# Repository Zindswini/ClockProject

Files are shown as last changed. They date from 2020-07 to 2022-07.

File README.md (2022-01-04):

# ClockProject V2.0
This is the GitHub Companion to the Large scale RGB LED Clock as shown in [VIDEO IN PROGRESS]
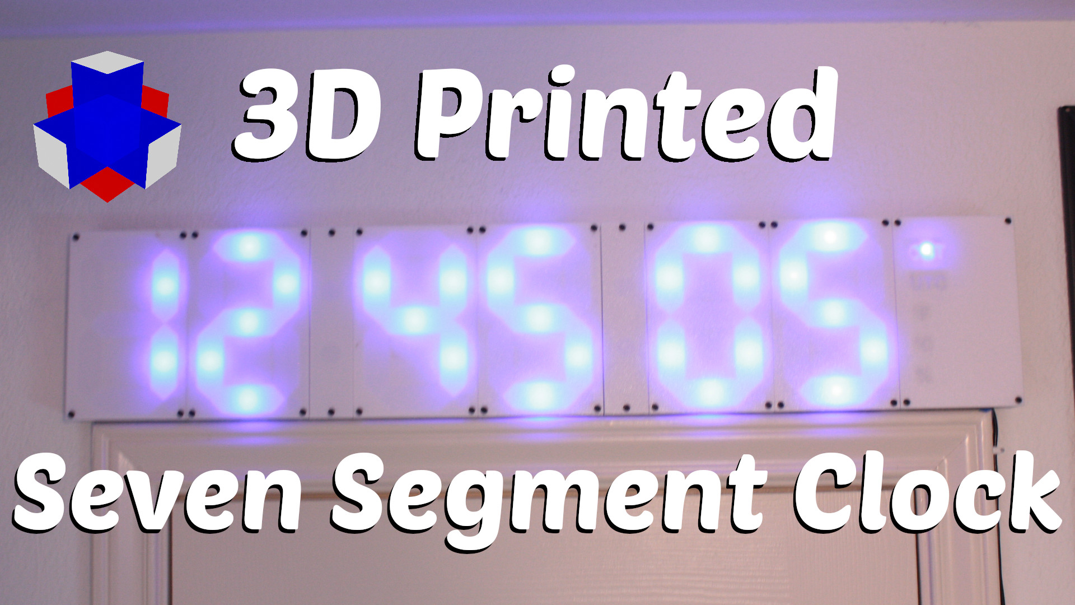
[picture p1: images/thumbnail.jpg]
Thumbnail
 
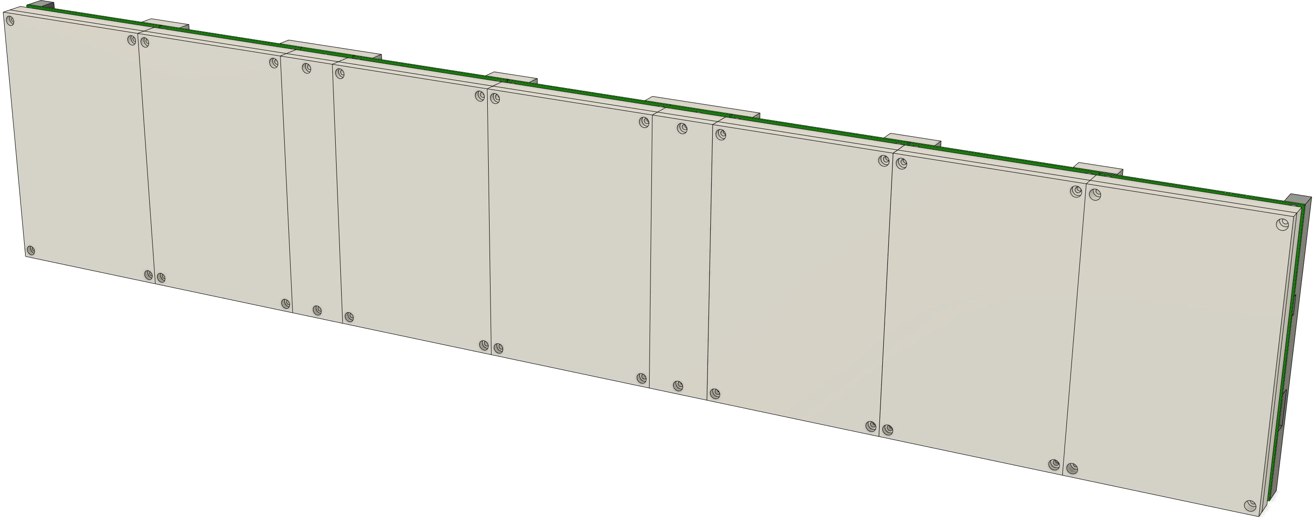
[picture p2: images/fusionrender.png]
Fusion Render
TablePicture 

# Design Files
- 3D and Circuit design was completed using Autodesk Fusion 360. Exports from the project are provided.
- Manufacturing was completed through JLC PCB, Gerber files exported from Fusion 360 are provided.

# Dependencies & Building
This project uses PlatformIO to manage dependencies. In theory, this should mean that you will not have to worry about dependencies and versioning. Just in case, a list of used libraries is provided below.

In order to program your own clock, you need to provide the appropriate credentials for your Wifi network. In order to connect, update the STASSID and STAPSK fields.

This project relies on:
### Libraries:
- [Adafruit ESP8266](https://github.com/adafruit/Adafruit_ESP8266) (In Library Browser)
- [Arduino JSON](https://github.com/bblanchon/ArduinoJson/tree/5.x)  (In Library Browser) (*Note version 5.x*)
- [DHTesp](https://github.com/beegee-tokyo/DHTesp) (In Library Browser)
- [NTPClient](https://github.com/arduino-libraries/NTPClient) (In Library Browser)
- [TelnetStream](https://github.com/jandrassy/TelnetStream) (In Library Browser)

### ESP Board
Add http://arduino.esp8266.com/stable/package_esp8266com_index.json to the "Additional Board Manager URLs" in the Arduino IDE, then add the esp8266 from inside the board manager.

Be sure to select "Adafruit Feather HUZZAH ESP8266" when compiling.

(this might be obsolete now that the project uses PlatformIO)

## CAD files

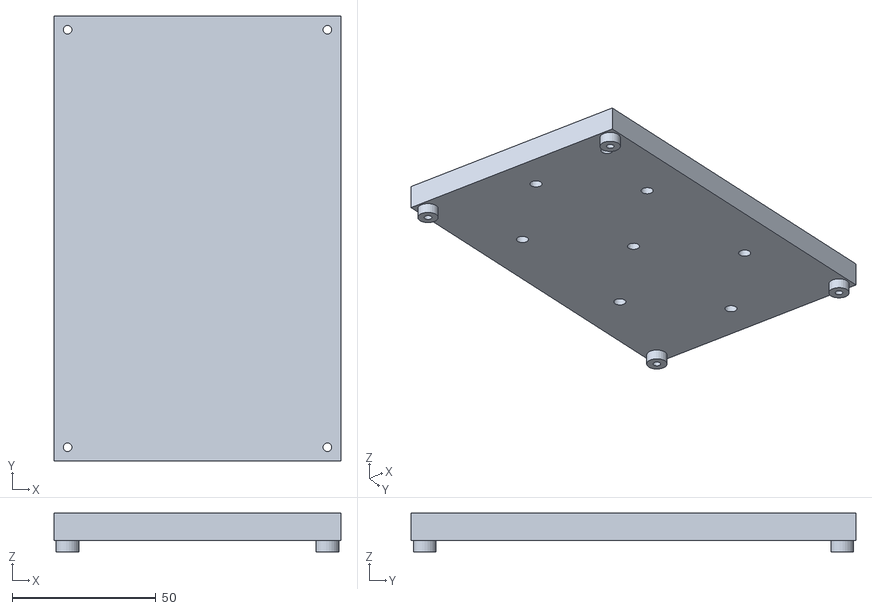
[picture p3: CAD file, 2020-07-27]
3D Files/STLs/Display Back Plate.stl
100.0 x 155.0 x 13.5

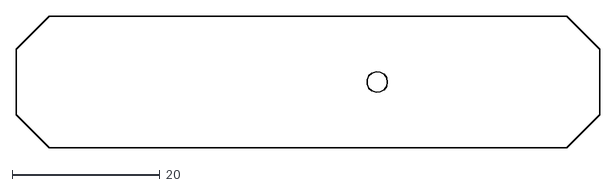
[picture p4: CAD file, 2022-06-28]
cad/3D/pcb_profile.dxf
79.1 x 17.8

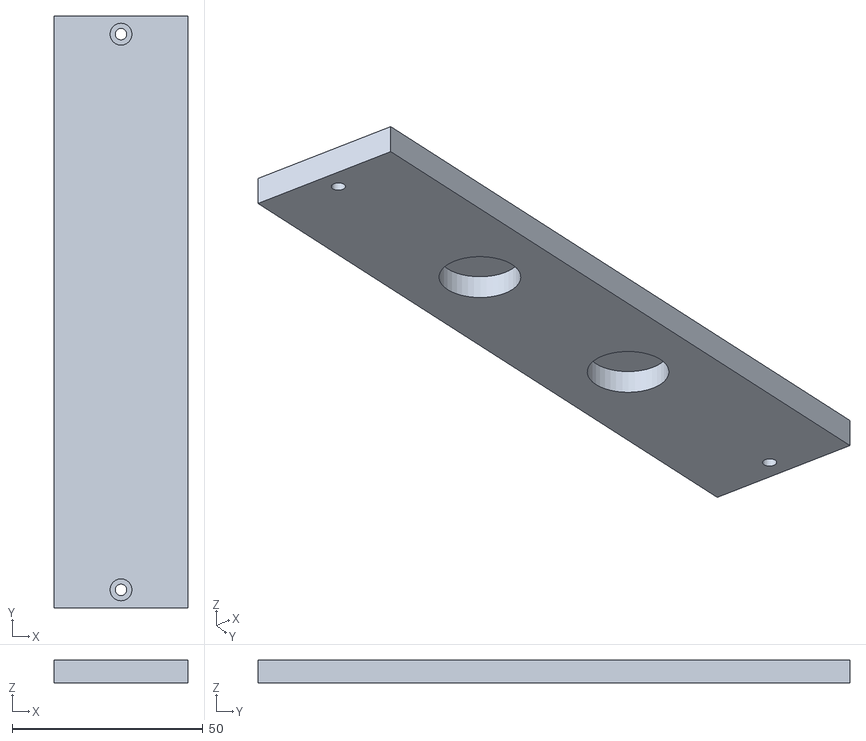
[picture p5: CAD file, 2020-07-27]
3D Files/STLs/Tick Front Plate.stl
35.0 x 155.0 x 6.00

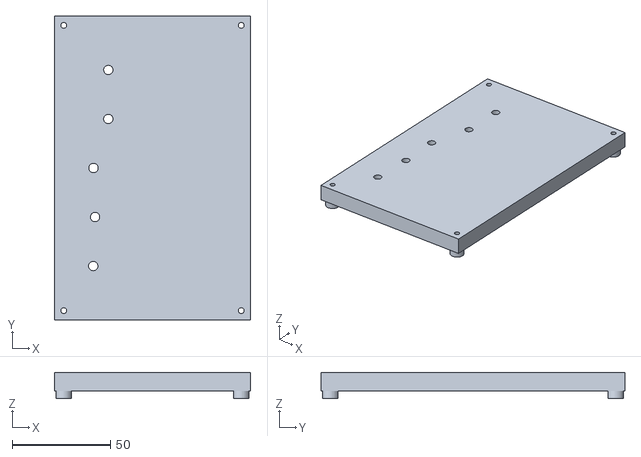
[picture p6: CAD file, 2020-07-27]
3D Files/STLs/Controller Back Plate.stl
100.0 x 155.0 x 13.5

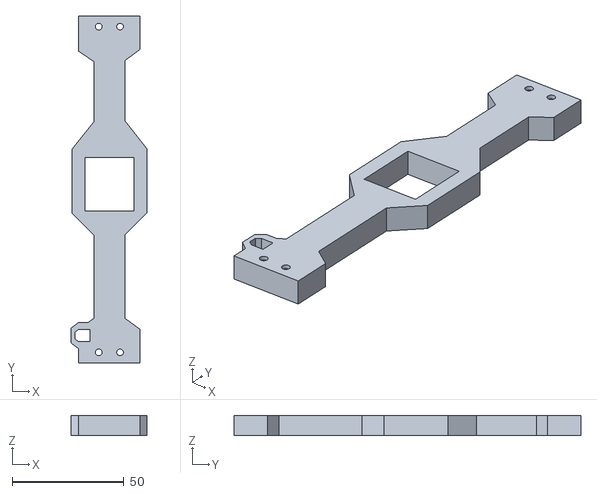
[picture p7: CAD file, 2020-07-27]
3D Files/STLs/Display Joiner.stl
33.9 x 155.0 x 9.00

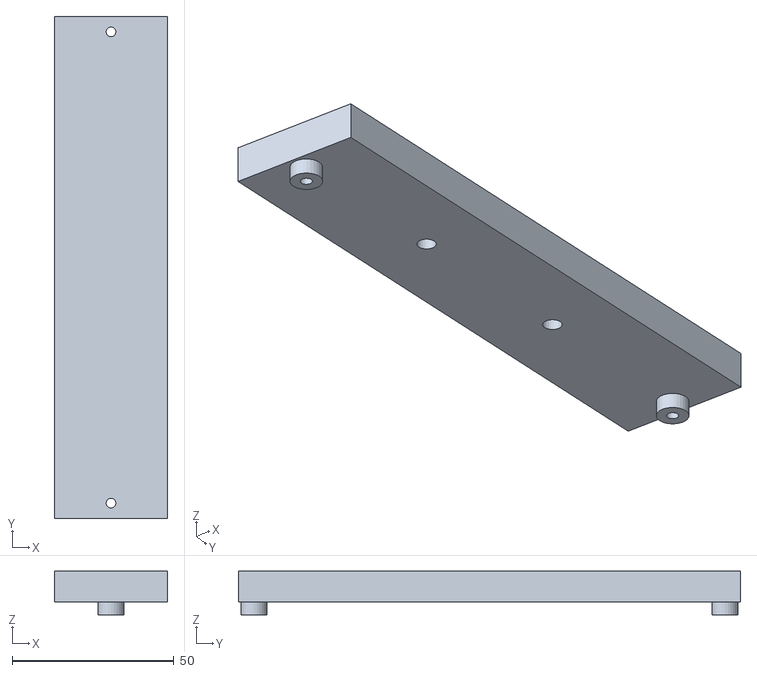
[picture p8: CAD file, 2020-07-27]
3D Files/STLs/Tick Back Plate.stl
35.0 x 155.0 x 13.5

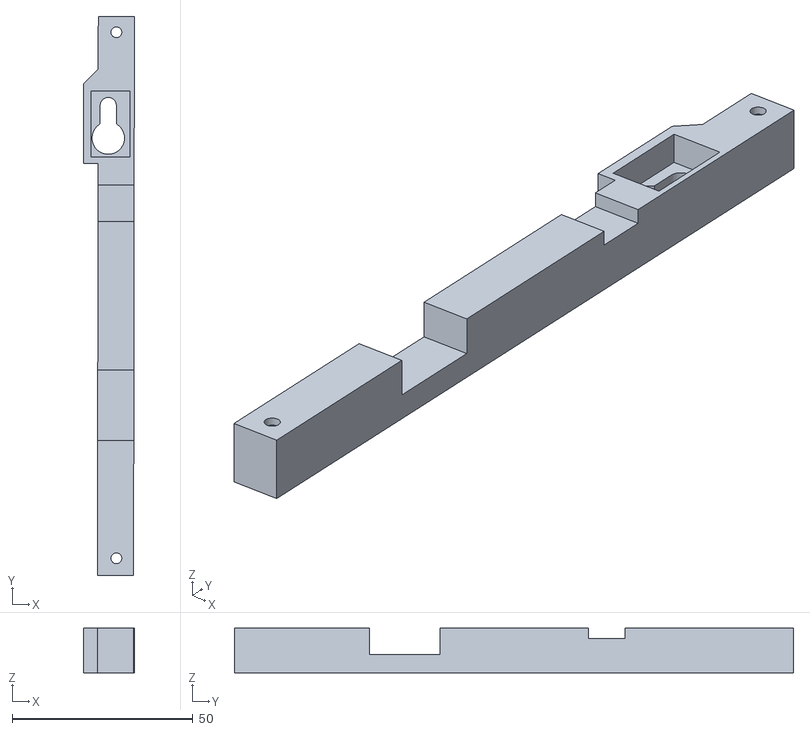
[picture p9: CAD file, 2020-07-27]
3D Files/STLs/Right Wall Mount.stl
14.1 x 154.6 x 12.4

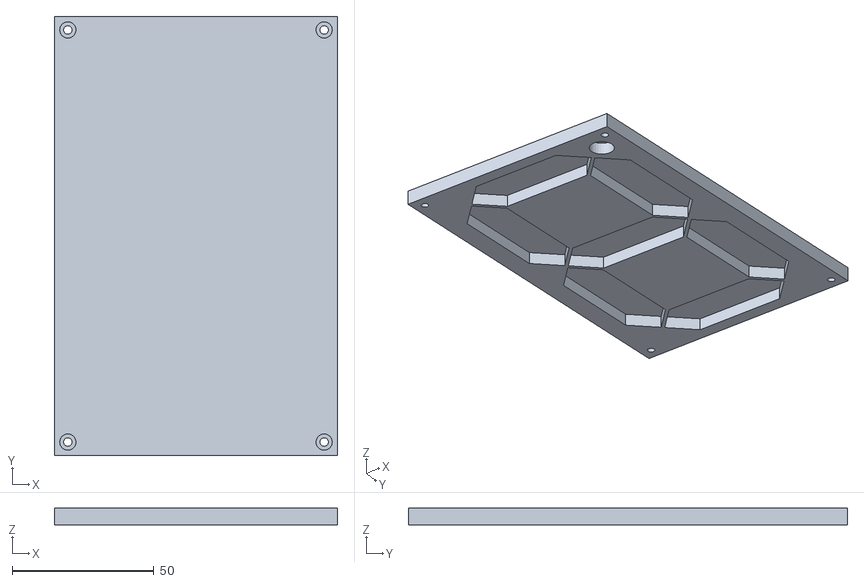
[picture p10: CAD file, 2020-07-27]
3D Files/STLs/Display Front Plate.stl
100.0 x 155.0 x 6.00

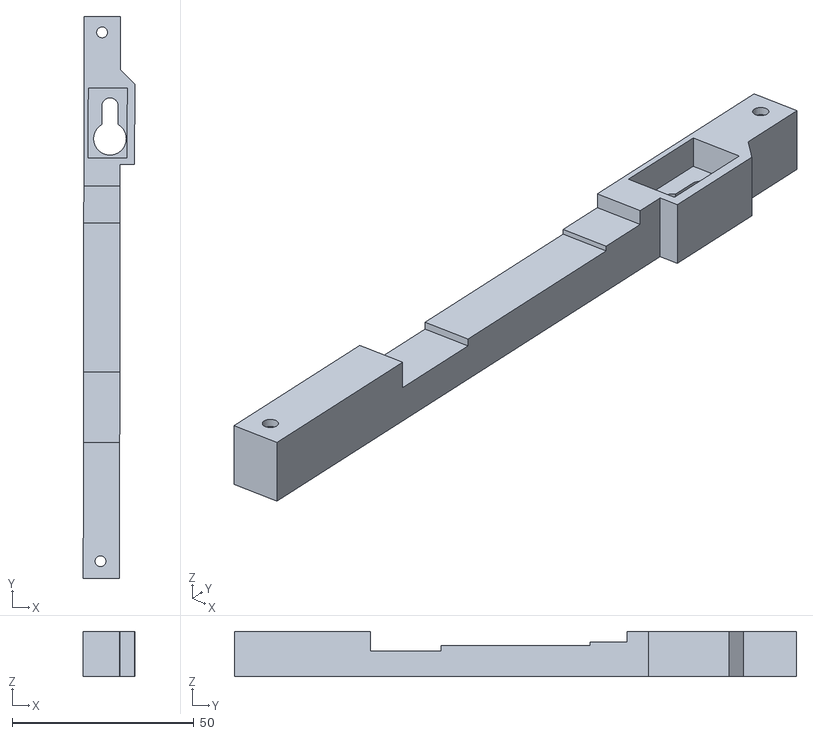
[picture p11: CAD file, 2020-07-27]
3D Files/STLs/Left Wall Mount.stl
14.2 x 154.6 x 12.4

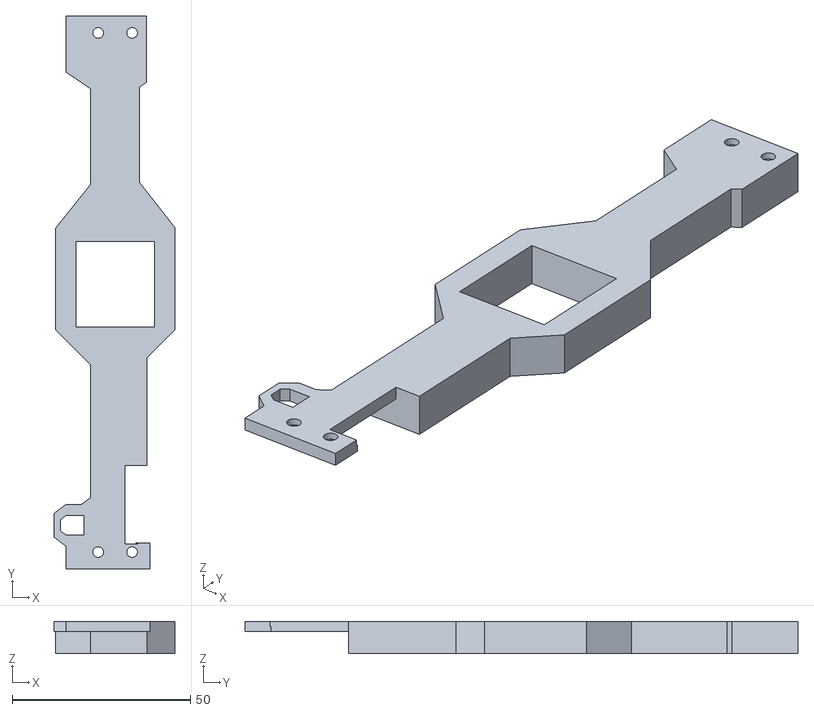
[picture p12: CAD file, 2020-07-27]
3D Files/STLs/Controller Joiner.stl
33.9 x 155.0 x 9.00

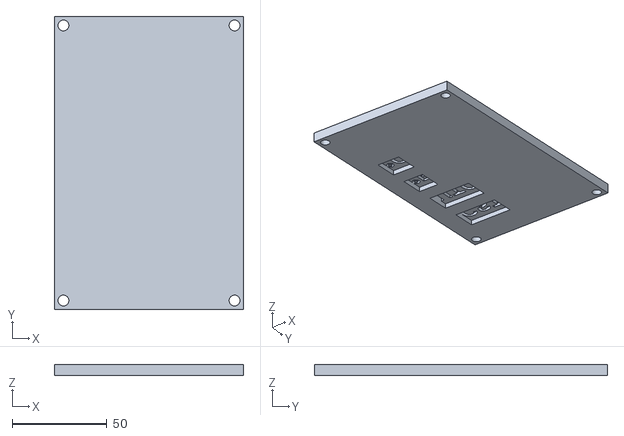
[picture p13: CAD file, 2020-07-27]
3D Files/STLs/Controller Front Plate.stl
100.0 x 155.0 x 6.00

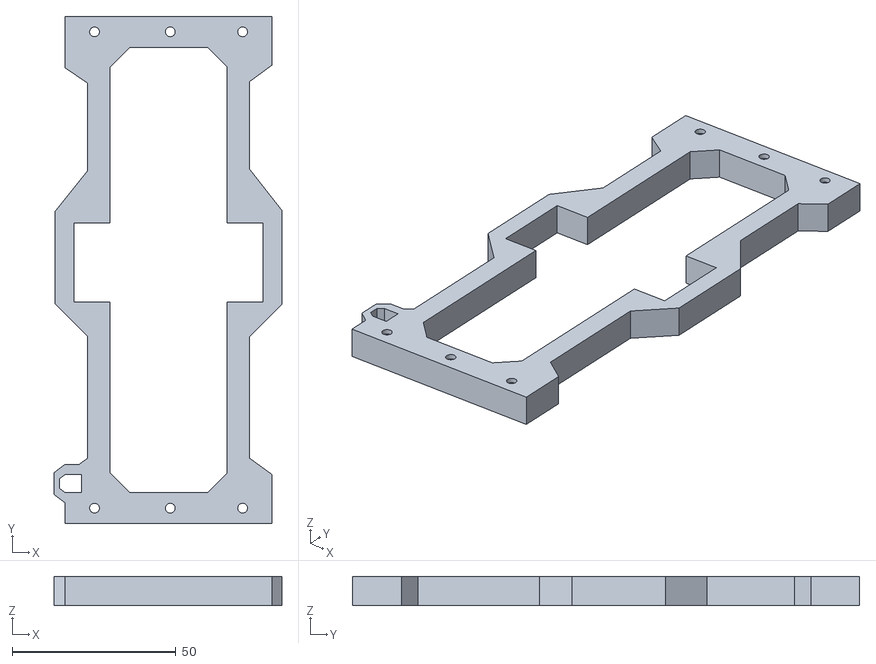
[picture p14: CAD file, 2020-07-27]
3D Files/STLs/Tick Joiner.stl
69.7 x 155.0 x 9.00

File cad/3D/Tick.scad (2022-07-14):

$fn=15;
panel_Height=160;

// Derived Variables
grid = panel_Height / 16;
panel_Width=grid*10;


//Led spacing parameters
led_side_width=6;
led_package_depth=4;

//Chamber Parameters
circle_diameter=grid*1.65;
midpoint_spacing=grid*1.65;
chamber_depth=4;

//Top Diffuser Parameters
diffuse_depth=0.75;


//ETC
screw_diameter=2.8;
screw_distance=1.5*grid;

bridging_helper_size=0.2;
bridging_padding = 1;

chanfer = 5;

pcb_depth = 3;

led_depth = led_package_depth + pcb_depth;

//Show/hide elements
led_layer = true;
chamber = false;
bridge_helpers = false;
diffuse_layer = false;

pcb_mode = false;

if (pcb_mode){
    led_layer = false;
    chamber = false;
    bridge_helpers = false;
    diffuse_layer = false;
    pcb_depth = 0;
    
    pcb_link([0,0,0], 0, true);
}



//Define major points
a = [5 * grid, 14 * grid, 0];
b = [8 * grid, 11 * grid, 0];
c = [8 * grid, 5 * grid, 0];
d = [5 * grid, 2 * grid, 0];
e = [2 * grid, 5 * grid, 0];
f = [2 * grid, 11 * grid, 0];
g = [5 * grid, 8 * grid, 0];
//h = [1 * grid, 1 * grid, 0];

points = [a, b, c, d, e, f, g];

render() difference(){
    union(){
        //Led Layer
        if (led_layer) difference() {
            cube([panel_Width, panel_Height, led_depth]);
            for(i=points)
            {
                translate(i - [led_side_width/2, led_side_width/2, 0])
                    cube([led_side_width, led_side_width, led_depth], false);
            }
        }
        
        
        //Chamber Layer
        if(chamber){
            translate([0, 0, led_depth]){
                difference() {
                    cube([panel_Width, panel_Height, chamber_depth]);
                    
                    //Horizontal
                    for(i=[a, d, g]) { chamber(i, 0); }
                    
                    //Vertical
                    for(i=[b, c, e, f]) { chamber(i, 90); }
                }
            }
        }
        
        //Diffuse Layer
        if(diffuse_layer){
            translate([0,0,led_depth + chamber_depth]){
                cube([panel_Width, panel_Height, diffuse_depth]);
            }
        }
    }

    //Corner Screw Holes
    screw([screw_distance, screw_distance, 0]);
    screw([panel_Width - screw_distance, panel_Height - screw_distance,0]);
    screw([panel_Width - screw_distance,screw_distance,0]);
    screw([screw_distance,panel_Height - screw_distance,0]);

    side_chanfer([0,0,0], 0);
    side_chanfer([panel_Width, panel_Height-chanfer-chanfer, 0], 180);

    //PCB Slots
    if (!pcb_mode){
        pcb_link(f, 45);
        pcb_link(a, -45);
        pcb_link(b, 225);
        pcb_link(g, 225);
        pcb_link(e, -45);
        pcb_link(d, 45);

        //pcb_link(f + [10,10,0], -45);
    }
}

pcb_edge_right([0*grid, 8*grid, -pcb_depth]);
//pcb_edge_left([0,0,0]);

module pcb_link(position, zAngle, profile=false){
    if(!profile) { union(){
        linear_extrude(pcb_depth) pcb_profile(position, zAngle);
        translate(position) rotate([0,0,zAngle])screw([distance_formula(a,b)/2, 0, 0]);
    }}
    else { pcb_profile(position, zAngle); }
}

module pcb_edge_left(position, zAngle=0, profile=false){
    if(!profile) { union(){
        linear_extrude(pcb_depth) pcb_profile_left(position, zAngle);
        translate(position) rotate([0,0,zAngle])screw([distance_formula(a,b)/2, 0, 0]);
    }}
    else { pcb_profile_left(position, zAngle); }
}

module pcb_edge_right(position, zAngle=0, profile=false){
    if(!profile) { union(){
        translate(position) linear_extrude(pcb_depth) pcb_profile_right([0,0,0], zAngle);
        translate(position) rotate([0,0,zAngle])screw([distance_formula(a,b)/2, 0, 0]);
    }}
    else { pcb_profile_right(position, zAngle); }
}

module pcb_profile(position, zAngle){
    pcb_grid = grid/3;
    distance = distance_formula(a,b) - (2*pcb_grid);
    translate(position) rotate([0,0,zAngle + 180]) difference(){
        polygon(points=[
            [2*pcb_grid, 1*pcb_grid],
            [1*pcb_grid, 2*pcb_grid],
            [-distance + 1*pcb_grid, 2*pcb_grid],
            [-distance, 1*pcb_grid],
            [-distance, -1*pcb_grid],
            [-distance + 1*pcb_grid, -2*pcb_grid],
            [1*pcb_grid, -2*pcb_grid],
            [2*pcb_grid, -1*pcb_grid]
        ]);
        if(pcb_mode){ translate([distance_formula(a,b)/2, 0, 0]) circle(screw_diameter/2); }
    }
}

module pcb_profile_left(position, zAngle){
    pcb_grid = pcb_width/2;
    translate(position) rotate([0,0,zAngle]) difference(){
        hull(){
            translate([distance_formula(a,b), 0, 0]) rotate([0,0,-90]) translate([0,-3*pcb_grid,0]) polygon(points=[[-pcb_grid * 2,0], [-pcb_grid, pcb_grid], [pcb_grid, pcb_grid], [pcb_grid * 2,0]]);
            translate([0,0,0]) rotate([0,0,90]) translate([0,1*pcb_grid,0]) polygon(points=[[-pcb_grid * 2,0], [-pcb_grid, pcb_grid], [pcb_grid, pcb_grid], [pcb_grid * 2,0]]);
        } 
        translate([distance_formula(a,b)/2, 0, 0]) circle(screw_diameter/2);
    }
}

module pcb_profile_right(position, zAngle){
    pcb_grid = grid/2;
    translate(position) rotate([0,0,zAngle]) {
        translate([0,0,0]) rotate([0,0,0]) polygon(points=[
            [0,pcb_grid],
            [pcb_grid, 2*pcb_grid],
            [pcb_grid, 4*pcb_grid],
            [2*pcb_grid, 5*pcb_grid],
            [3*pcb_grid, 4*pcb_grid],
            [3*pcb_grid, 0],
            [2*pcb_grid, -pcb_grid],
            [0,-pcb_grid]
            ]);
        translate([distance_formula(a,b)/2, 0, 0]) circle(screw_diameter/2);
    }
}

module side_chanfer(position, rotation) {
    total_height = led_depth+chamber_depth+diffuse_depth;
    translate(position + [0,chanfer,total_height - chanfer]) rotate([90,0,90+rotation]) { linear_extrude(height=panel_Width)
        difference(){
            polygon(points=[[-chanfer,chanfer], [-chanfer,0],[0,chanfer]]);
            sector(chanfer, [90,180]);
        }

    }
}

module screw(position, length=(led_depth+chamber_depth)){
    translate(position) cylinder(length, screw_diameter/2, screw_diameter/2, false);
}

module chamber(position, zAngle){
    translate(position){
        rotate([0,0,zAngle]){
            difference(){
                hull(){
                    translate([-midpoint_spacing,0,0]) cylinder(chamber_depth, circle_diameter/2, circle_diameter/2);
                    translate([midpoint_spacing,0,0]) cylinder(chamber_depth, circle_diameter/2, circle_diameter/2);
                }
                if(bridge_helpers){
                    translate([0,0,bridging_helper_size/2]) cube([led_side_width+bridging_padding, circle_diameter, bridging_helper_size], true);
                }
            }
        }
    }
}

// Pillaged from here: https://openhome.cc/eGossip/OpenSCAD/SectorArc.html
module sector(radius, angles) {
    r = radius / cos(180 / $fn);
    step = -360 / $fn;

    points = concat([[0, 0]],
        [for(a = [angles[0] : step : angles[1] - 360]) 
            [r * cos(a), r * sin(a)]
        ],
        [[r * cos(angles[1]), r * sin(angles[1])]]
    );

    difference() {
        circle(radius, $fn = $fn + 20);
        polygon(points);
    }
}

function distance_formula(a,b) = sqrt( (b[0] - a[0])^2 + (b[1] - a[1])^2 );

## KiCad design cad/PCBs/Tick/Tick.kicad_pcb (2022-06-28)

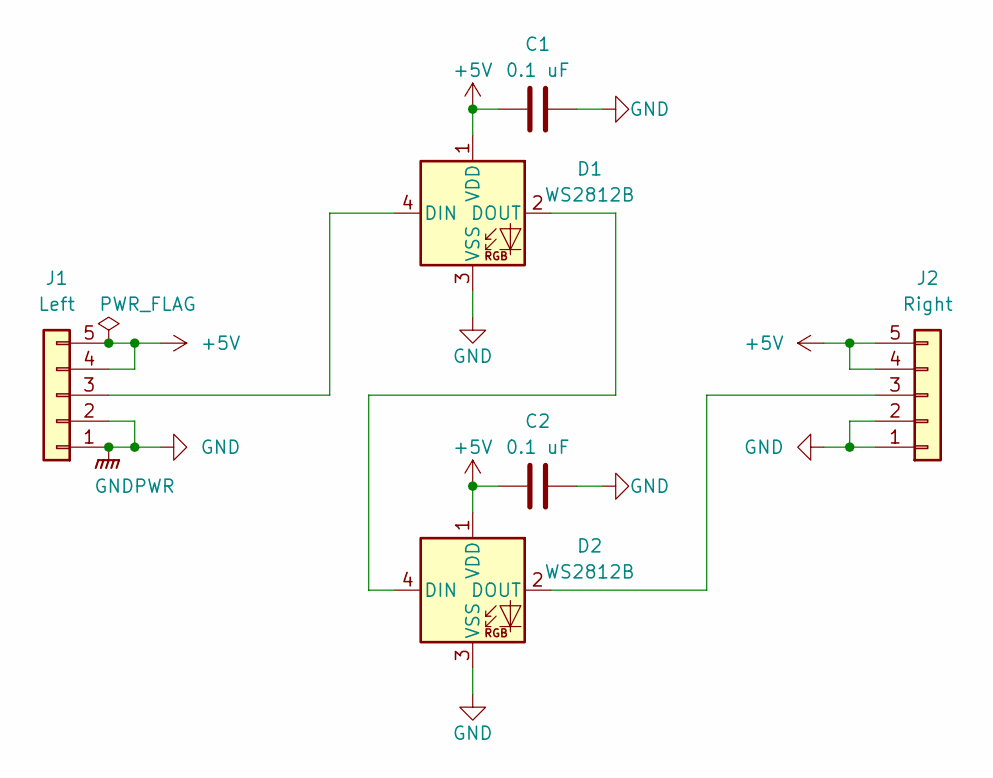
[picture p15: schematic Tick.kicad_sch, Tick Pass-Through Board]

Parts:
C1, C2: 0.1 uF; C_0805_2012Metric
D1, D2: WS2812B; LED_WS2812B_PLCC4_5.0x5.0mm_P3.2mm
J1: Left; PinHeader_1x05_P2.54mm_Horizontal
J2: Right; PinHeader_1x05_P2.54mm_Horizontal

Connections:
+5V: C1.2, C2.2, D1.1 (VDD), D2.1 (VDD), J1.4, J1.5, J2.4, J2.5
GND: C1.1, C2.1, D1.3 (VSS), D2.3 (VSS), J1.1, J1.2, J2.1, J2.2
unnamed: D1.2 (DOUT), D2.4 (DIN)
unnamed: D1.4 (DIN), J1.3
unnamed: D2.2 (DOUT), J2.3

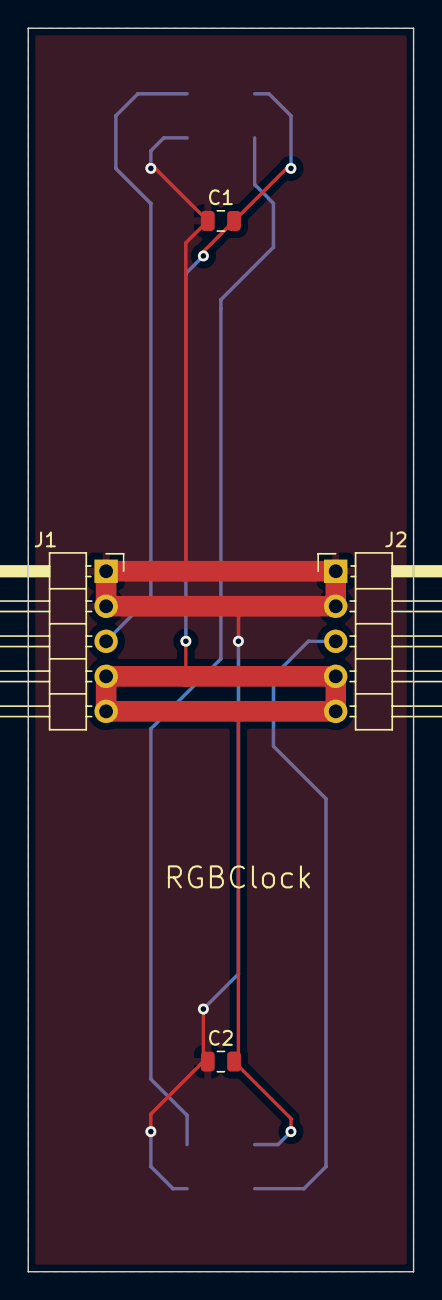
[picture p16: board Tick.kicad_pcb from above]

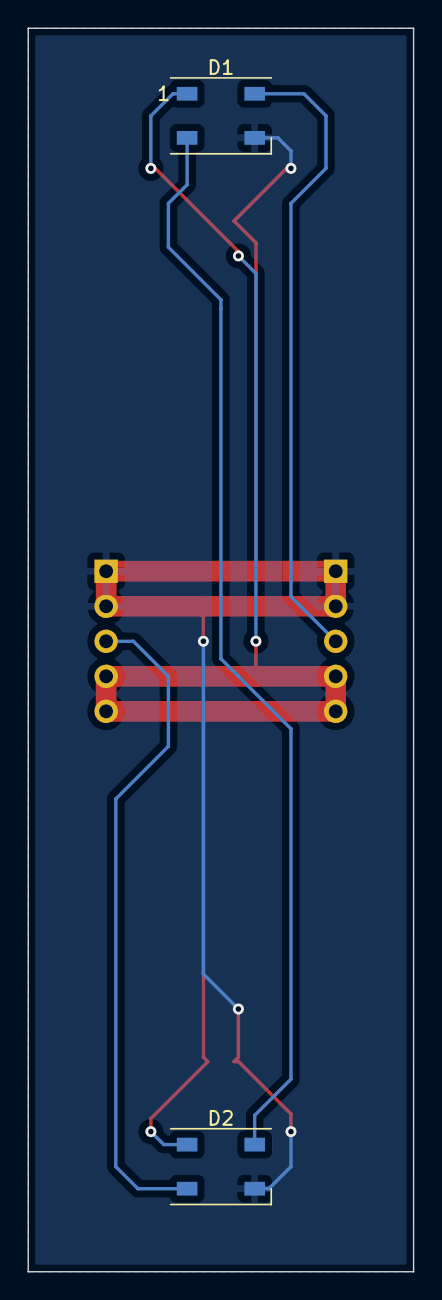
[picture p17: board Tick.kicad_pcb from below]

Board: 2 copper layers, 27.9 x 90.2 mm, 6 parts (2 on the bottom side), 5 nets.

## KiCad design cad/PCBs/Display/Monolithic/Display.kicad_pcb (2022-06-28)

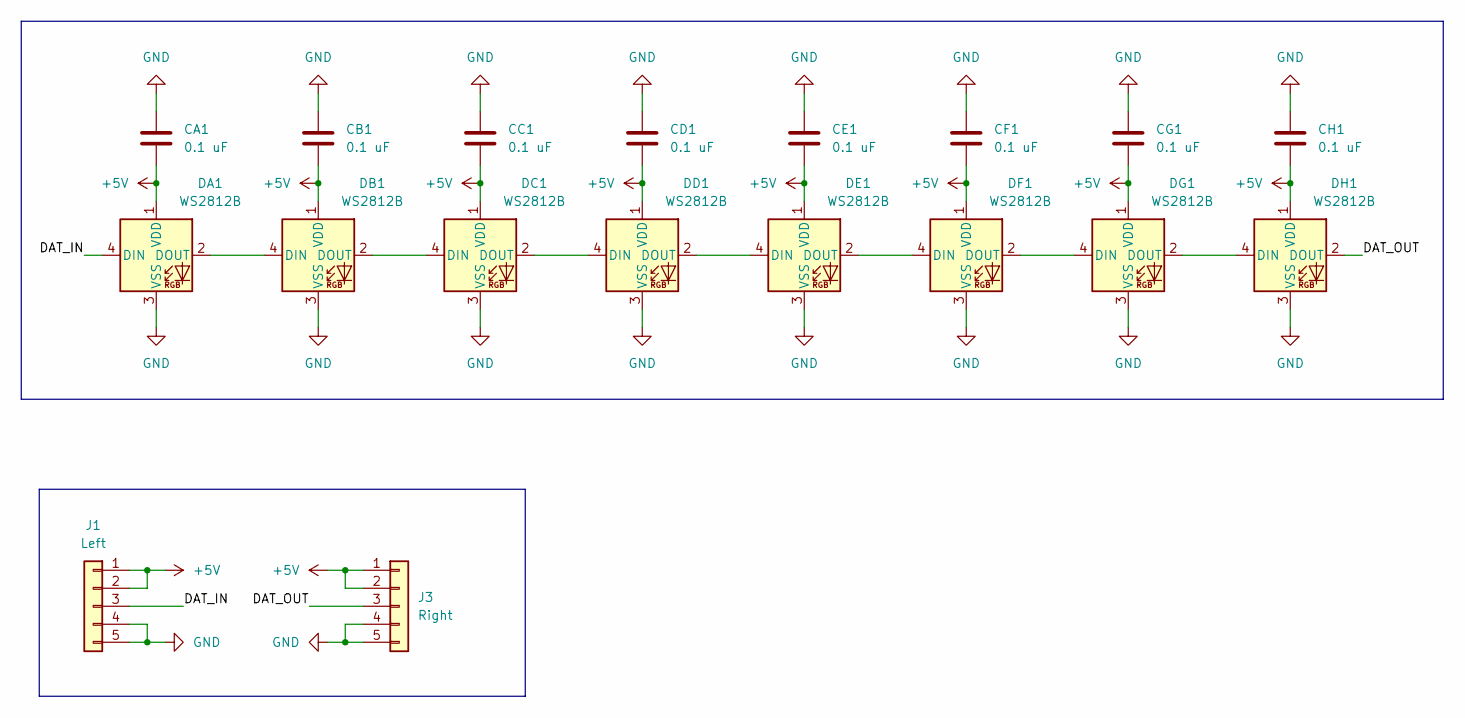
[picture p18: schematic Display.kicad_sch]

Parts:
CA1: 0.1 uF; C_0805_2012Metric
CB1: 0.1 uF; C_0805_2012Metric
CC1: 0.1 uF; C_0805_2012Metric
CD1: 0.1 uF; C_0805_2012Metric
CE1: 0.1 uF; C_0805_2012Metric
CF1: 0.1 uF; C_0805_2012Metric
CG1: 0.1 uF; C_0805_2012Metric
CH1: 0.1 uF; C_0805_2012Metric
DA1: WS2812B; LED_WS2812B_PLCC4_5.0x5.0mm_P3.2mm
DB1: WS2812B; LED_WS2812B_PLCC4_5.0x5.0mm_P3.2mm
DC1: WS2812B; LED_WS2812B_PLCC4_5.0x5.0mm_P3.2mm
DD1: WS2812B; LED_WS2812B_PLCC4_5.0x5.0mm_P3.2mm
DE1: WS2812B; LED_WS2812B_PLCC4_5.0x5.0mm_P3.2mm
DF1: WS2812B; LED_WS2812B_PLCC4_5.0x5.0mm_P3.2mm
DG1: WS2812B; LED_WS2812B_PLCC4_5.0x5.0mm_P3.2mm
DH1: WS2812B; LED_WS2812B_PLCC4_5.0x5.0mm_P3.2mm
J1: Left; PinHeader_1x05_P2.54mm_Horizontal
J3: Right; PinHeader_1x05_P2.54mm_Horizontal

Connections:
+5V: CA1.2, CB1.2, CC1.2, CD1.2, CE1.2, CF1.2, CG1.2, CH1.2, DA1.1 (VDD), DB1.1 (VDD), DC1.1 (VDD), DD1.1 (VDD), DE1.1 (VDD), DF1.1 (VDD), DG1.1 (VDD), DH1.1 (VDD), J1.1, J1.2, J3.1, J3.2
/DAT_IN: DA1.4 (DIN), J1.3
/DAT_OUT: DH1.2 (DOUT), J3.3
GND: CA1.1, CB1.1, CC1.1, CD1.1, CE1.1, CF1.1, CG1.1, CH1.1, DA1.3 (VSS), DB1.3 (VSS), DC1.3 (VSS), DD1.3 (VSS), DE1.3 (VSS), DF1.3 (VSS), DG1.3 (VSS), DH1.3 (VSS), J1.4, J1.5, J3.4, J3.5
unnamed: DA1.2 (DOUT), DB1.4 (DIN)
unnamed: DB1.2 (DOUT), DC1.4 (DIN)
unnamed: DC1.2 (DOUT), DD1.4 (DIN)
unnamed: DD1.2 (DOUT), DE1.4 (DIN)
unnamed: DE1.2 (DOUT), DF1.4 (DIN)
unnamed: DF1.2 (DOUT), DG1.4 (DIN)
unnamed: DG1.2 (DOUT), DH1.4 (DIN)

Board: 2 copper layers, 18 parts (0 on the bottom side), 11 nets, no tracks yet.

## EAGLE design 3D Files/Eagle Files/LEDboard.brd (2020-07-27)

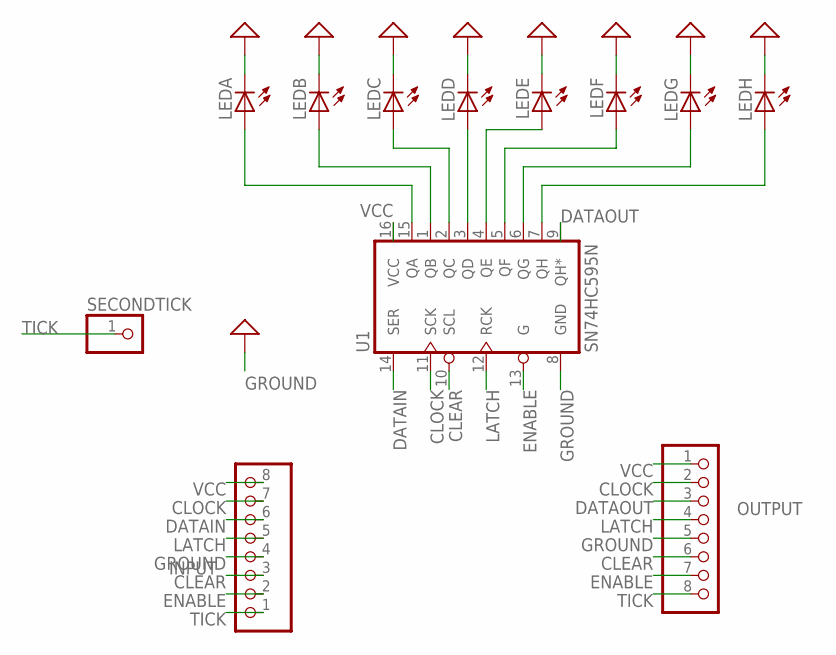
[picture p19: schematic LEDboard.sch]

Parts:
INPUT: PINHD-1X8/90; 1X08/90
LEDA: LED5MM
LEDB: LED5MM
LEDC: LED5MM
LEDD: LED5MM
LEDE: LED5MM
LEDF: LED5MM
LEDG: LED5MM
LEDH: LED5MM
OUTPUT: PINHD-1X8/90; 1X08/90
SECONDTICK: PINHD-1X1; 1X01
U1: SN74HC595N; DIP16

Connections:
CLEAR: INPUT.3, OUTPUT.6, U1.10 (SCL)
CLOCK: INPUT.7, OUTPUT.2, U1.11 (SCK)
DATAIN: INPUT.6, U1.14 (SER)
DATAOUT: OUTPUT.3, U1.9 (QH*)
ENABLE: INPUT.2, OUTPUT.7, U1.13 (G)
GND: LEDA.K (C), LEDB.K (C), LEDC.K (C), LEDD.K (C), LEDE.K (C), LEDF.K (C), LEDG.K (C), LEDH.K (C)
GROUND: INPUT.4, OUTPUT.5, U1.8 (GND)
LATCH: INPUT.5, OUTPUT.4, U1.12 (RCK)
unnamed: LEDD.A, U1.3 (QD)
unnamed: LEDA.A, U1.15 (QA)
unnamed: LEDB.A, U1.1 (QB)
unnamed: LEDC.A, U1.2 (QC)
unnamed: LEDE.A, U1.4 (QE)
unnamed: LEDF.A, U1.5 (QF)
unnamed: LEDG.A, U1.6 (QG)
unnamed: LEDH.A, U1.7 (QH)
TICK: INPUT.1, OUTPUT.8, SECONDTICK.1
VCC: INPUT.8, OUTPUT.1, U1.16 (VCC)

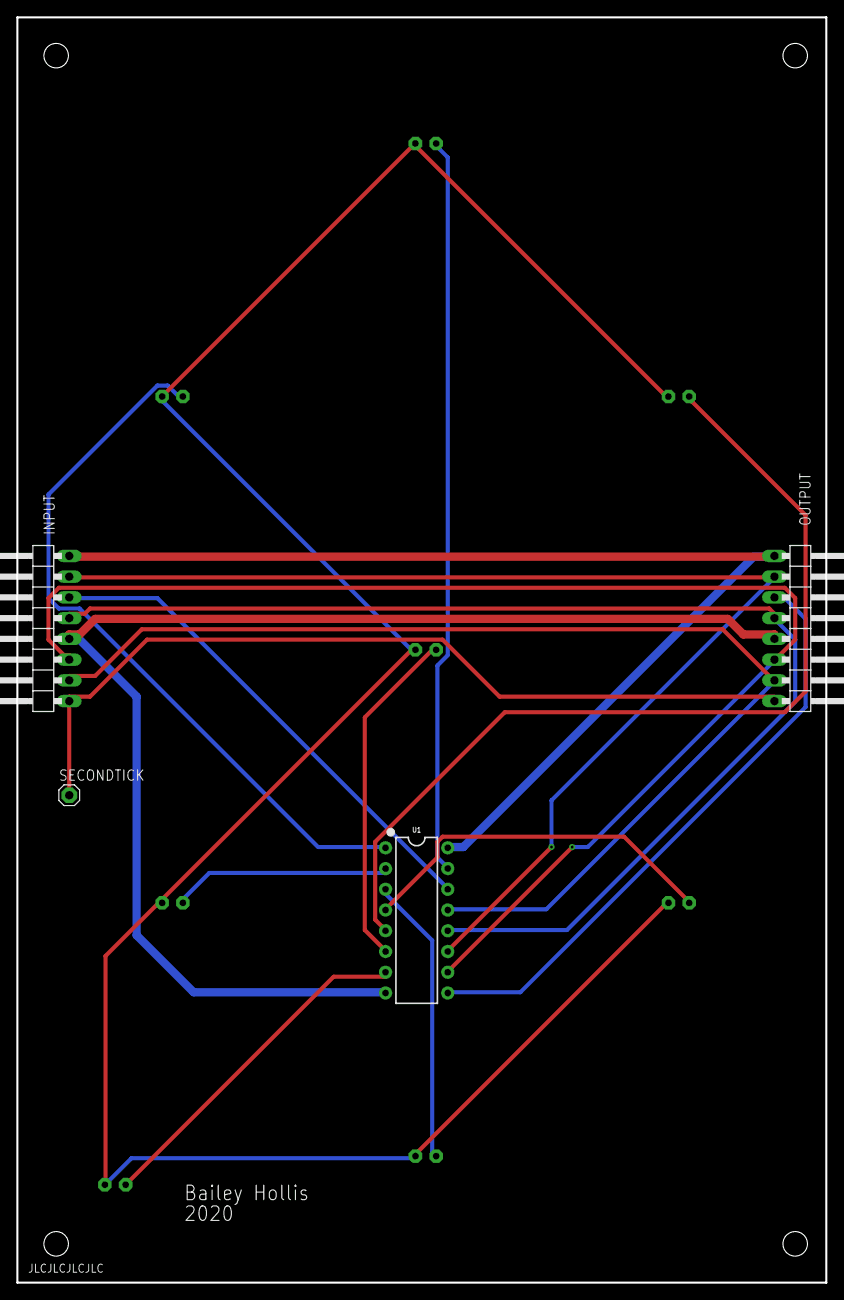
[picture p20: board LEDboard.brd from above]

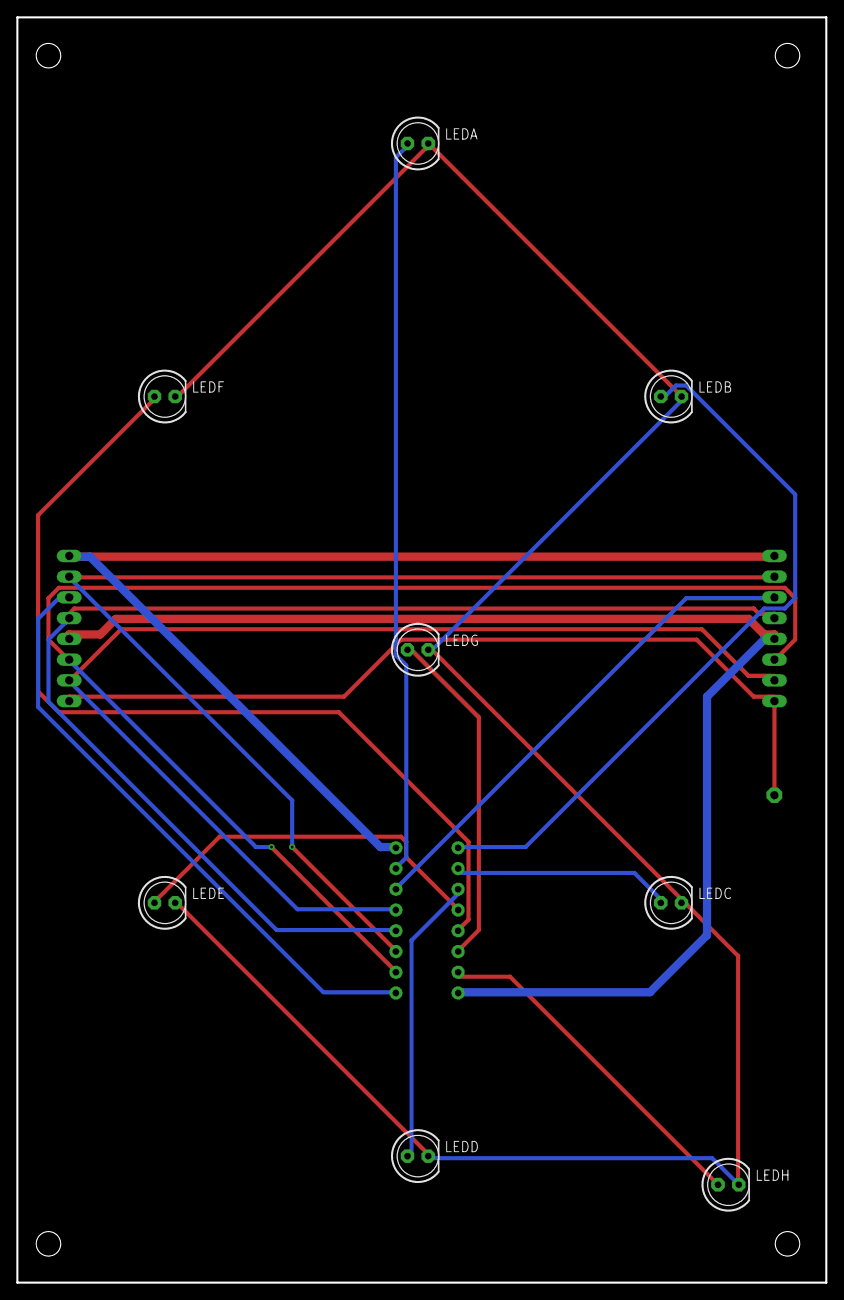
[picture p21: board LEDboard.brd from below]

Board: 2 copper layers, 99.1 x 154.9 mm, 12 parts (8 on the bottom side), 18 nets.

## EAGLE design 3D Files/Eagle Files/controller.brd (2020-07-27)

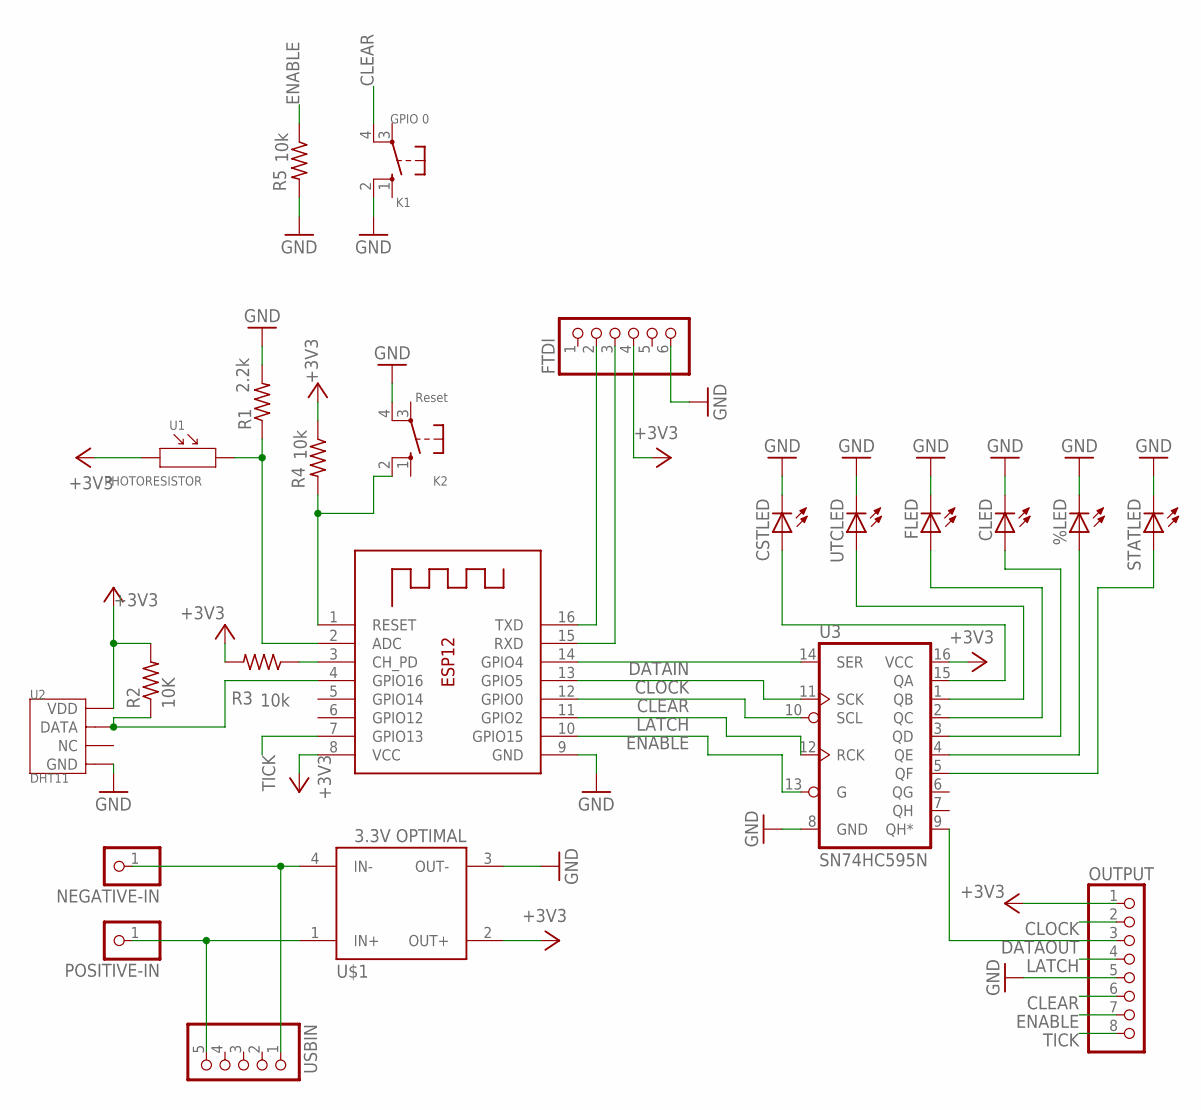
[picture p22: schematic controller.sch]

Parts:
%LED: LED5MM
CLED: LED5MM
CSTLED: LED5MM
FLED: LED5MM
FTDI: PINHD-1X6/90; 1X06/90
K1: GPIO 0; B3F-40XX
K2: Reset; B3F-40XX
NEGATIVE-IN: PINHD-1X1; 1X01
OUTPUT: PINHD-1X8/90; 1X08/90
POSITIVE-IN: PINHD-1X1; 1X01
R1: 2.2k; 0204/7
R2: 10K; 0204/7
R3, R4, R5: 10k; 0204/7
STATLED: LED5MM
U1: PHOTORESISTOR; SNR2-3.0
U2: DHT11; SNR4-2.54-15.5X12.0X5.5MM
U3: SN74HC595N; DIP16
U$1: 3.3V OPTIMAL; DIODFN1720X2240X160-4N
USBIN: PINHD-1X5; 1X05
UTCLED: LED5MM
X1: ESP-12

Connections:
+3V3: FTDI.4, OUTPUT.1, R2.2, R3.2, R4.1, U1.1, U2.1 (VDD), U3.16 (VCC), U$1.2 (OUT+), X1.8 (VCC)
CLEAR: K1.4 (P1), OUTPUT.6, U3.10 (SCL), X1.12 (GPIO0)
CLOCK: OUTPUT.2, U3.11 (SCK), X1.13 (GPIO5)
DATAIN: U3.14 (SER), X1.14 (GPIO4)
DATAOUT: OUTPUT.3, U3.9 (QH*)
ENABLE: OUTPUT.7, R5.1, U3.13 (G), X1.10 (GPIO15)
GND: %LED.K (C), CLED.K (C), CSTLED.K (C), FLED.K (C), FTDI.6, K1.2 (S1), K2.4 (P1), OUTPUT.5, R1.2, R5.2, STATLED.K (C), U2.4 (GND), U3.8 (GND), U$1.3 (OUT-), UTCLED.K (C), X1.9 (GND)
LATCH: OUTPUT.4, U3.12 (RCK), X1.11 (GPIO2)
unnamed: CSTLED.A, U3.15 (QA)
unnamed: U3.1 (QB), UTCLED.A
unnamed: NEGATIVE-IN.1, U$1.4 (IN-), USBIN.1
unnamed: POSITIVE-IN.1, U$1.1 (IN+), USBIN.5
unnamed: R1.1, U1.2, X1.2 (ADC)
unnamed: FLED.A, U3.2 (QC)
unnamed: CLED.A, U3.3 (QD)
unnamed: %LED.A, U3.4 (QE)
unnamed: STATLED.A, U3.5 (QF)
unnamed: R3.1, X1.3 (CH_PD)
unnamed: R2.1, U2.2 (DATA), X1.4 (GPIO16)
unnamed: FTDI.2, X1.16 (TXD)
unnamed: FTDI.3, X1.15 (RXD)
unnamed: K2.2 (S1), R4.2, X1.1 (RESET)
TICK: OUTPUT.8, X1.7 (GPIO13)

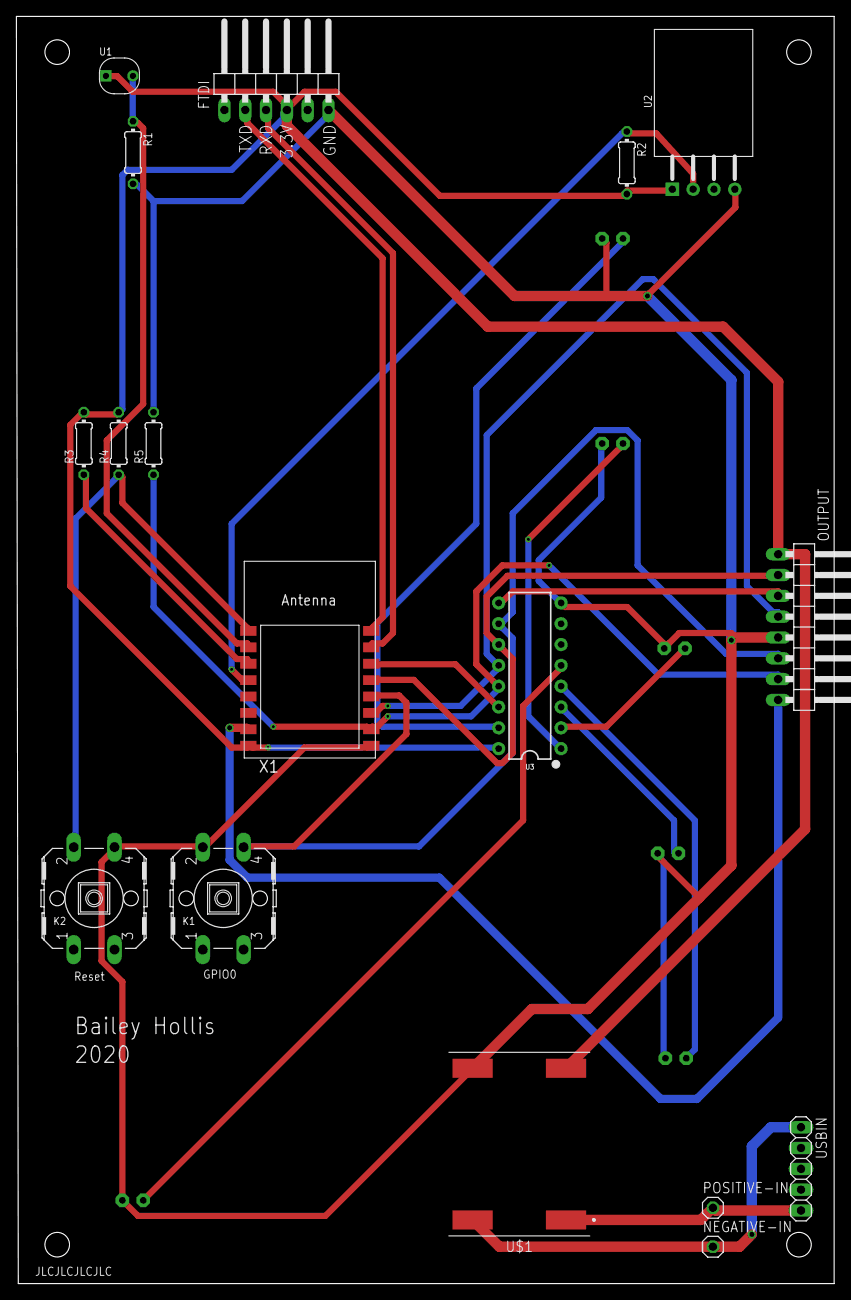
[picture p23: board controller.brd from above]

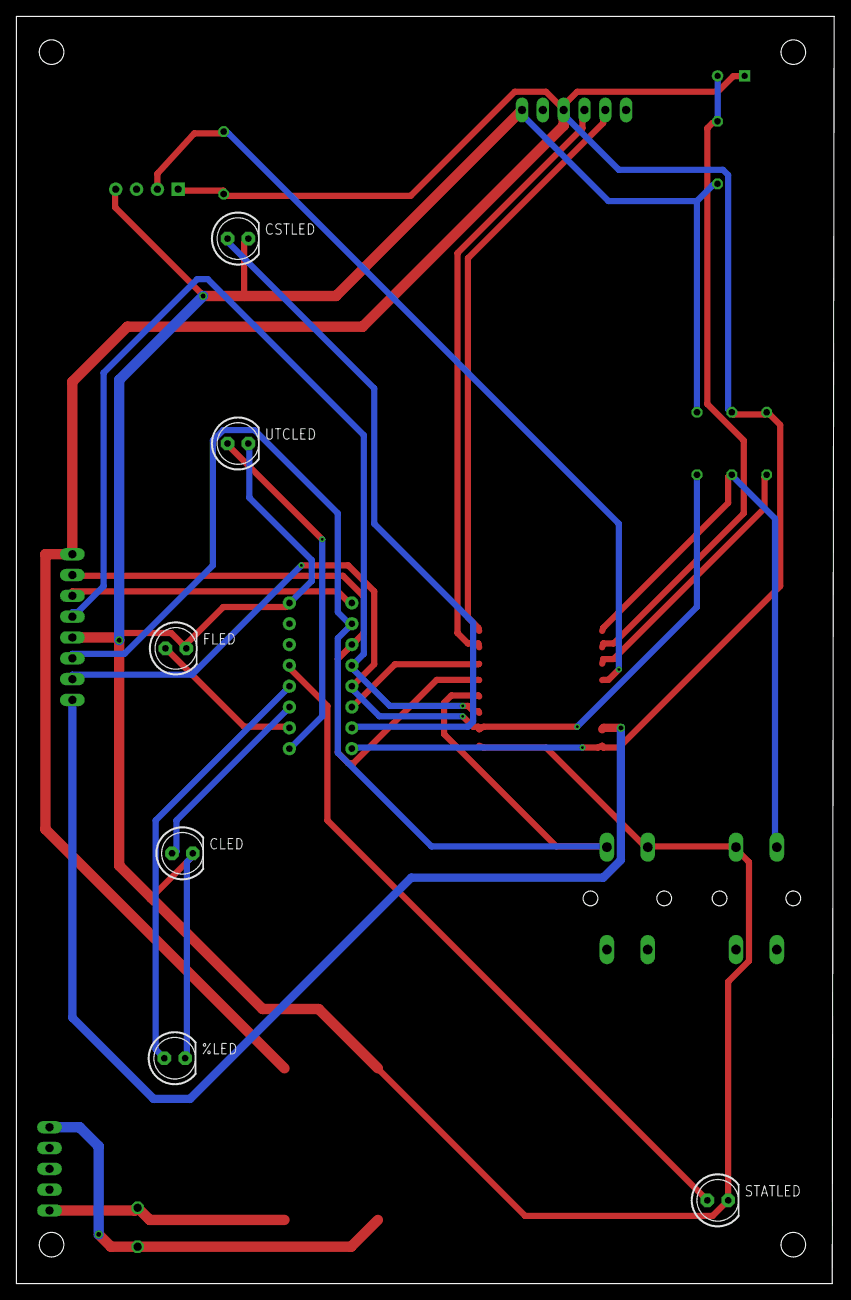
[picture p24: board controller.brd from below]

Board: 2 copper layers, 99.8 x 154.6 mm, 23 parts (6 on the bottom side), 23 nets.

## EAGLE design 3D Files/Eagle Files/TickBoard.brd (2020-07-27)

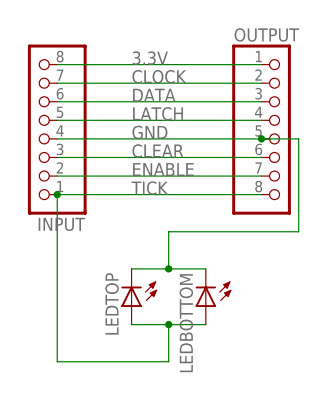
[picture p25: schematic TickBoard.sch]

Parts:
INPUT: PINHD-1X8/90; 1X08/90
LEDBOTTOM: LED5MM
LEDTOP: LED5MM
OUTPUT: PINHD-1X8/90; 1X08/90

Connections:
3.3V: INPUT.8, OUTPUT.1
CLEAR: INPUT.3, OUTPUT.6
CLOCK: INPUT.7, OUTPUT.2
DATA: INPUT.6, OUTPUT.3
ENABLE: INPUT.2, OUTPUT.7
GND: INPUT.4, LEDBOTTOM.K (C), LEDTOP.K (C), OUTPUT.5
LATCH: INPUT.5, OUTPUT.4
TICK: INPUT.1, LEDBOTTOM.A, LEDTOP.A, OUTPUT.8

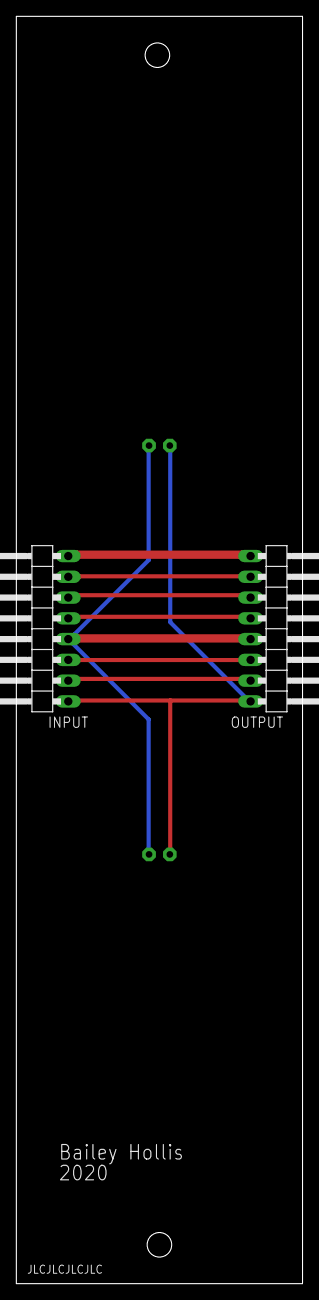
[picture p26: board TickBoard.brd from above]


Board: 2 copper layers, 35.0 x 155.0 mm, 4 parts (2 on the bottom side), 8 nets.

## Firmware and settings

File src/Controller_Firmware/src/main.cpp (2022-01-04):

#include <ArduinoJson.h>
#include <DHTesp.h>
#include <NTPClient.h>
#include <WiFiClientSecure.h>
#include "credentials.h"
#include "OTA.h"

//define I/O pins
#define DHT_PIN 16
#define LSESNSOR_PIN A0

#define DATAOUT 5
#define CLOCK 4
#define CLEAR 0
#define LATCH 2
#define ENABLE 15
#define TICK 13

//WORKING VARS
//init dht11 vars
double localHumidity;
double localTemperature;
double lastTemp;
DHTesp dht;

double outsideHumidity;
double outsideTemperature;

double timeOffset = 0.0;
int brightness;

//init wifi and ntp vars
WiFiUDP ntpUDP;
NTPClient timeClient(ntpUDP, "pool.ntp.org", utcOffsetInSeconds);

//init temp vars
int mode = 0;
bool switched = false;
bool fadeDir;

//init number definitions
byte numbs[12];

void pulse(int pin)
{
  digitalWrite(pin, HIGH);
  digitalWrite(pin, LOW);
}

void dip(int pin)
{
  digitalWrite(pin, LOW);
  digitalWrite(pin, HIGH);
}

//Two digits max (duh)
void shiftNumber(int num)
{
  if(num < 10){
        shiftOut(DATAOUT,CLOCK, LSBFIRST,numbs[0]);
        shiftOut(DATAOUT,CLOCK, LSBFIRST,numbs[num]);
      }
      else{
        shiftOut(DATAOUT,CLOCK, LSBFIRST,numbs[num/10]);
        shiftOut(DATAOUT,CLOCK, LSBFIRST,numbs[num % 10]);
      }  
}

void shiftEmpty()
{
  digitalWrite(DATAOUT, LOW);
  for(int i = 0; i < 8; i++) { pulse(CLOCK); }
}

//properly handle single and triple digit temps
void shiftTemperature(int inTemp, int outTemp)
{
  inTemp = constrain(inTemp, 0, 999);
  outTemp = constrain(outTemp, 0, 999);
  
  if(outTemp <= 99) { shiftNumber(outTemp); shiftEmpty(); }
  else
  {
    shiftNumber(outTemp / 10);
    shiftOut(DATAOUT,CLOCK, LSBFIRST,numbs[outTemp % 10]);
  }
  
  if(inTemp <= 99) { shiftEmpty(); shiftNumber(inTemp);}
  else
  {
    shiftNumber(inTemp / 10);
    shiftOut(DATAOUT,CLOCK, LSBFIRST,numbs[inTemp % 10]);
  }
}

String formatNumber(int in)
{
  if(in < 10) { return "0"+(String)in; }
  else { return (String)in; }
}

float convertToFahrenheit(float inTemp) { return inTemp * (9.00/5) + 32; }

void shifterOut(int hr, int mn, int sec, int mode)
{
  //clear,shiftChar, latch
  switch (mode)
  {
    case 0: //Local time
      //calculate time difference
      int locHr;
      locHr = hr + utcOffsetInHours;
      if(locHr < 0){ locHr += 24; }
      else if(locHr > 24) { locHr -= 24; }

      if(twelvehr && locHr > 12){ locHr -= 12; }
      
      //Shift hour, minute, second
      shiftNumber(locHr);
      shiftNumber(mn);
      shiftNumber(round(sec + timeOffset));
      //Serial.println(locHr);
      break;

    case 1: //UST time
      if(twelvehr && hr > 12){ hr -= 12; }
      
      shiftNumber(hr);
      shiftNumber(mn);
      shiftNumber(round(sec + timeOffset));
      break;

    case 2: //Temp F
      shiftTemperature(round(convertToFahrenheit(localTemperature)),round(convertToFahrenheit(outsideTemperature)));
      break;

    case 3: //Temp C
      //shift outside temp
      shiftTemperature(round(localTemperature),round(outsideTemperature));
      break;

    case 4: //Humid %
      shiftTemperature(round(localHumidity),round(outsideHumidity));
      break;
  }
}



void startWifi()
{
  Serial.println();
  Serial.print("connecting to ");
  Serial.println(ssid);
  WiFi.mode(WIFI_STA);
  WiFi.begin(ssid, password);
  while (WiFi.status() != WL_CONNECTED) {
    delay(500);
    Serial.print(".");
  }
  Serial.println("");
  Serial.println("WiFi connected");
  Serial.println("IP address: ");
  Serial.println(WiFi.localIP());
}

void shiftMode(int currentMode)
{
  digitalWrite(DATAOUT, HIGH);
  pulse(CLOCK);
  pulse(CLOCK);
  pulse(CLOCK);
  for(int i = 4; i >= 0; i--){
    if(currentMode == i)
    {
      digitalWrite(DATAOUT, HIGH);
    }
    else
    {
      digitalWrite(DATAOUT, LOW);
    }
    //digitalWrite(DATAOUT, HIGH);
    pulse(CLOCK);
  }
}


void changeMode()
{
  //change mode
  mode++;
  if(mode > 4) { mode=0; }

  //uncomment to disable UTC
  if(mode == 1) { mode++; }
  //uncomment to disable farenheit
  //if(mode == 2) { mode++; }
  //uncomment to disable celsius
  if(mode == 3) { mode++; }
  //uncomment to disable humidity
  if(mode == 4) { mode++; }
  
  if(mode > 4) { mode=0; }
  
  shifterOut(timeClient.getHours(),timeClient.getMinutes(),timeClient.getSeconds(),mode);
  shiftMode(mode);
  pulse(LATCH);
}



//thanks to RoboUlbricht on github for the demo code
void downloadData() {
  //connect to openweathermap
  WiFiClient client;
  Serial.print("connecting to ");
  Serial.println(host);
  if (!client.connect(host, 80)) {
    Serial.println("connection failed");
    return;
  }
  client.print(String("GET ") + param + " HTTP/1.1\r\n" +
               "Host: " + host + "\r\n" +
               "User-Agent: ESP8266\r\n" +
               "Connection: close\r\n\r\n");

  Serial.println("request sent");

  line = client.readStringUntil('\n');
  if (line != "HTTP/1.1 200 OK\r") {
    Serial.print("Unexpected response: ");
    Serial.println(line);
    return;
  }

  if (client.find("\r\n\r\n")) {
    DynamicJsonBuffer jsonBuffer(4096);
    JsonObject& root = jsonBuffer.parseObject(client);
    
    outsideTemperature = root["main"]["temp"];
    Serial.print("Temperature: ");
    Serial.println(outsideTemperature);

    outsideHumidity = root["main"]["humidity"];
    Serial.print("Humidity: ");
    Serial.println(outsideHumidity);
  } 
}

int updateBrightness()
{
  int count = 0;
  int value = 0;

  //attmept "denoising" by taking many readings
  for(int i = 0; i < 1000; i++){
  value += analogRead(A0);
  }
  value /= 1000;
  value /= 2;
  TelnetStream.println(value);
  if(value < lowAmbientBrightness){ value = 1; }
  else { value = 512; }
  

  value *= 2;
  return value;
}

//fade out, update screen, fade in. 512 resolution due to small decimals.
void fade()
{
  if(brightness < 1024)
  {
    //change mode
    changeMode();
  
    shifterOut(timeClient.getHours(),timeClient.getMinutes(),timeClient.getSeconds(),mode);
    shiftMode(mode);
    shifterOut(timeClient.getHours(),timeClient.getMinutes(),timeClient.getSeconds(),mode);
    shiftMode(mode);
    shifterOut(timeClient.getHours(),timeClient.getMinutes(),timeClient.getSeconds(),mode);
    shiftMode(mode);
    
    pulse(LATCH);
  }
  else{
  int fadebrightness = brightness / 2;
  //fade out
  while(fadebrightness > 0)
  {
    fadebrightness -= 1;
    analogWrite(ENABLE, 1024 - (fadebrightness * 2));
    delay(((fadeTime / 2) / brightness) * 10000);
    yield();
  }
  
  changeMode();
  
  //fade in
  while(fadebrightness < brightness / 2)
  {
    fadebrightness += 1;
    analogWrite(ENABLE, 1024 - (fadebrightness * 2));
    delay(((fadeTime / 2) / brightness) * 10000);
    yield();
  }
  }
  switched = false;
}




void setup() {
  pinMode(DATAOUT, OUTPUT);
  pinMode(CLOCK, OUTPUT);
  pinMode(CLEAR, OUTPUT);
  pinMode(LATCH, OUTPUT);
  //pinMode(TICK, OUTPUT);

  digitalWrite(CLEAR, HIGH);
  Serial.begin(115200);

  //Init services
  startWifi(); //takes a while
  timeClient.begin();
  timeClient.update();
  timeClient.setUpdateInterval(120);
  dht.setup(DHT_PIN, DHTesp::DHT11);

  //OTA
  ArduinoOTA.setHostname("Wall Clock");
  setupOTA();
  
  //Set initial register pins
  digitalWrite(CLEAR, HIGH);
  digitalWrite(ENABLE, LOW);

  //define Numbers
  numbs[0] =   0xFC;
  numbs[1] =   0x60;
  numbs[2] =   0xDA;
  numbs[3] =   0xF2;
  numbs[4] =   0x66;
  numbs[5] =   0xB6;
  numbs[6] =   0xBE;
  numbs[7] =   0xE0;
  numbs[8] =   0xFE;
  numbs[9] =   0xF6;
  numbs[10] =  0x51;
  numbs[11] = B00000000;
}

void loop() {
  //handle weather clock, brightness data updating
  
  /* //Handle mode switching
  if(timeClient.getSeconds() % timePer == 0)
  {
    if(switched == false){
      fade();
      switched = true;
    }
  }
  else if(switched == true) { switched = false; }
  */
  
  if(timeClient.getSeconds() % 30 == 0 && switched == false) 
  {
    downloadData();

    //update time and offset
    long startTime = millis();
    timeClient.update();
    timeOffset = (millis() - startTime) / 1000;
    
    localTemperature = dht.getTemperature();
    localTemperature = constrain(localTemperature,0,999);

    localHumidity = dht.getHumidity();
    localHumidity = constrain(localHumidity,0,999);
  }
  
  //update brightness and tick
  brightness = updateBrightness();
  
  analogWrite(ENABLE, 1024 - updateBrightness());
  
  if(timeClient.getSeconds() % 2 == 0 && brightness == 1024){analogWrite(TICK, brightness);}
  else { analogWrite(TICK, 0); } 

  ArduinoOTA.handle();

  //shift out main display
  shifterOut(timeClient.getHours(),timeClient.getMinutes(),timeClient.getSeconds(),mode);
  shiftMode(mode);
  pulse(LATCH);

  //handle Night vs Day framerate
  if(brightness < 1024){
    delay(1000);
  }
  else{
  delay(50);
  }

  }

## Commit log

2020-07-27 Images, Readme, Eagle files, Fusion files, STLs
    [Controller Back Plate.stl, Controller Front Plate.stl, Controller Joiner.stl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]
2022-05-26 Restructure files, init KiCad projects
    [Controller Back Plate.stl, Controller Front Plate.stl, Controller Joiner.stl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]
2022-06-28 Initial work in Kicad and OpenSCAD
    [Display.kicad_pcb, Display.kicad_sch, Tick.kicad_pcb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]
2022-07-14 Display CAD Progress
    [Tick.scad]
2023-10-15 Cleanup old file, test sync
    [Controller Back Plate.stl, Controller Front Plate.stl, Controller Joiner.stl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]

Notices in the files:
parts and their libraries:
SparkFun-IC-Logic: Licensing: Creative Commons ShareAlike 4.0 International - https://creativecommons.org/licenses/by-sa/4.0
